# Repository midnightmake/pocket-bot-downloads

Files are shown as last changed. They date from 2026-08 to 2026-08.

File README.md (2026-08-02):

# Pocket Bot Downloads

This repository contains all of the firmware, source files, courses, and STLs files you need to get started with the [Pocket Bot](https://www.midnightmake.com/products/pocket-bot).

## Contents

* `courses`: Various line and demo courses as seen in the [example programs](https://www.midnightmake.com/pages/pocket-bot-example-programs). Courses are provided as both `.docx` and `.pdf` files. If you'd like to generate your own barcode courses, you'll want the [course-encoder repository](https://github.com/midnightmake/course-encoder).
* `firmware`: Complete source code (drivers, firmware, etc.) for the Pocket Bot, inside a [Microchip Studio](https://www.microchip.com/en-us/tools-resources/develop/microchip-studio) project file. Also a great place to start for writing your own Pocket Bot applications.
* `stls`: 3D-printable replacment and expansion parts for the Pocket Bot. Assembly instructions are available [here](https://www.midnightmake.com/pages/pocket-bot-assembly).

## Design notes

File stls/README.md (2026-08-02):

# Overview
This folder contains STL files for the Pocket Bot.

A great deal of care has gone into making these parts easily 3D-printable with 0.2mm layer heights and no supports needed. Please see more details below.

## Description

This directory contains the following files:

* `chassis.stl`: The main Pocket Bot chassis.
* `marker-mount.stl`: An optional mount for an AprilTag (or similar) that snaps onto the optional expansion header.
* `round-table.stl`: A circular table intended to show off the **Area-Keeping** [example program](https://www.midnightmake.com/pages/pocket-bot-example-programs) by not falling off.
* `wheel-for-motor.stl`: A single wheel meant to be snapped to the Pocket Bot motor axis. **For best results, print this part with TPU or another rubber-like material.**
* `wheel-for-screw.stl`: A single wheel meant to be screwed onto the Pocket Bot to freely rotate. **For best results, print this part with TPU or another rubber-like material.**

Assembly instructions are available [here](https://www.midnightmake.com/pages/pocket-bot-assembly).

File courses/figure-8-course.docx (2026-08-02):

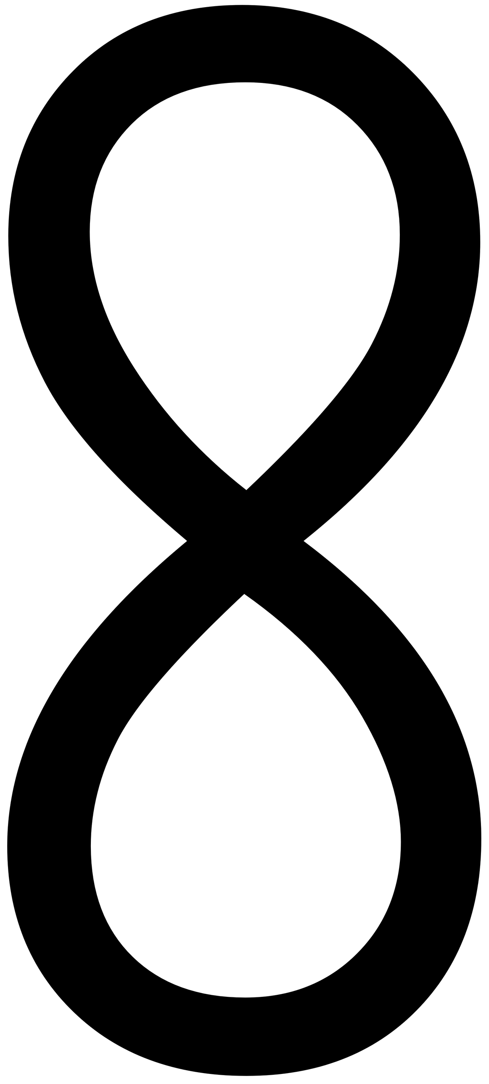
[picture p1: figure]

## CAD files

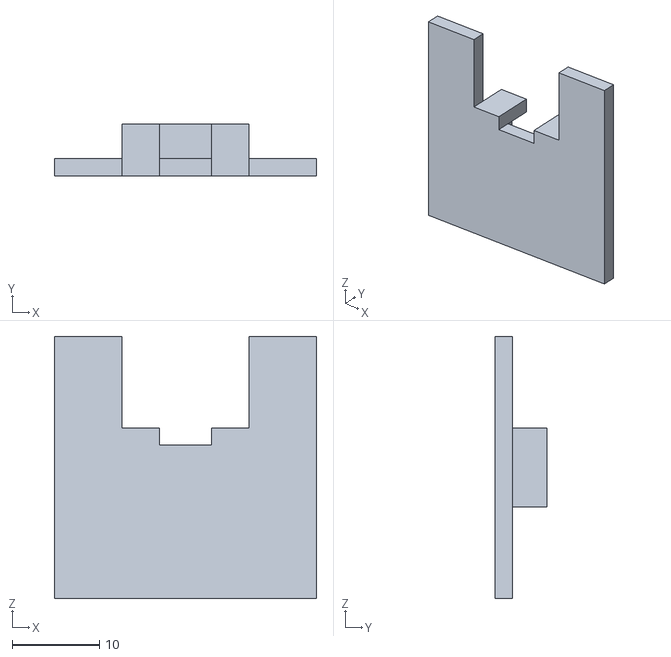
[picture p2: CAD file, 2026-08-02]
stls/marker-mount.stl
30.0 x 6.00 x 30.0

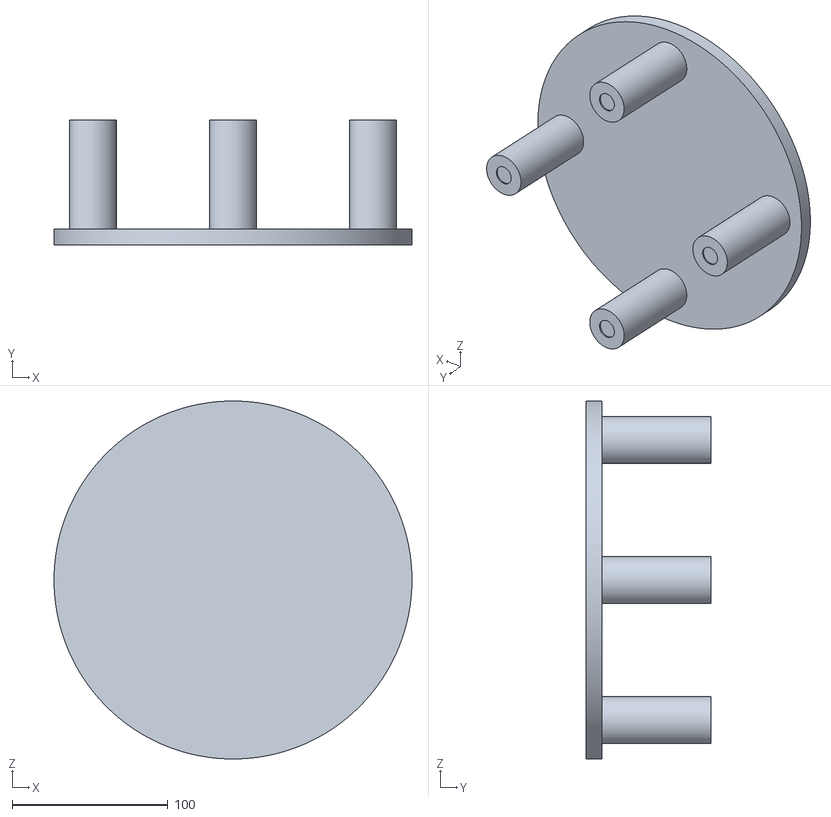
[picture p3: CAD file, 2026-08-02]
stls/round-table.stl
230.0 x 80.0 x 230.0

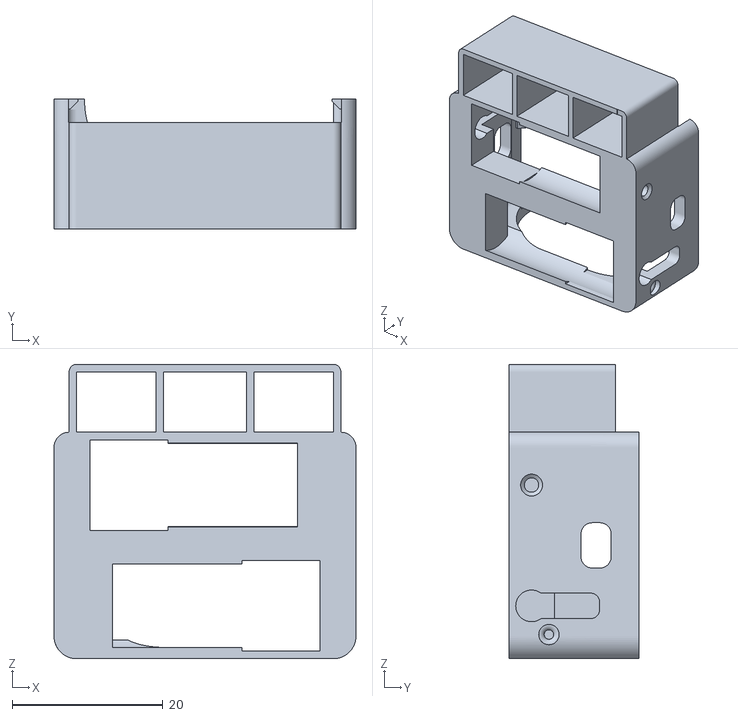
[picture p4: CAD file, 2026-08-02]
stls/chassis.stl
40.0 x 17.2 x 39.0

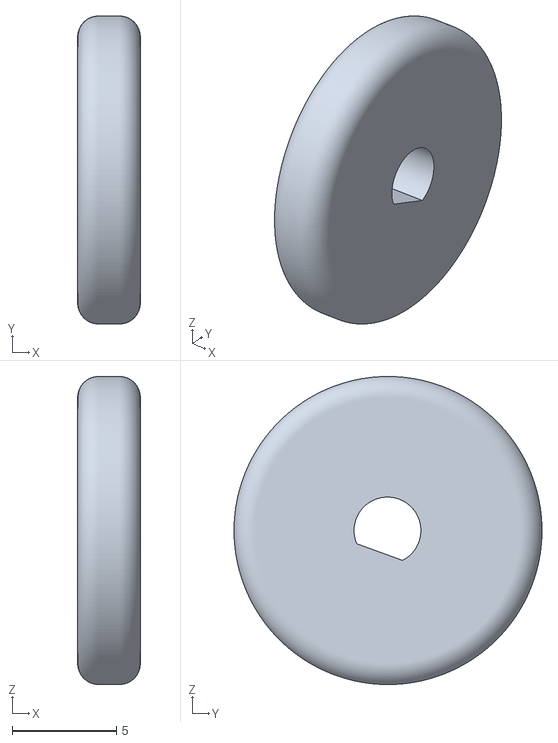
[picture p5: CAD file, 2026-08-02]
stls/wheel-for-motor.stl
3.00 x 14.7 x 14.7

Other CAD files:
stls/wheel-for-screw.stl

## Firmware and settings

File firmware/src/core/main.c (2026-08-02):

#include "drivers/clock.h"
#include "drivers/adc.h"
#include "drivers/motor.h"
#include "drivers/linesensor.h"
#include "drivers/led.h"
#include "drivers/button.h"

#include "programs/linefollowing.h"
#include "programs/fence.h"
#include "programs/barcode.h"
#include "programs/rave.h"
#include "programs/linedebug.h"
#include "programs/irforwarding.h"
#include "programs/visionclient.h"

#include "irmini/irmini.h"

#include "util/store.h"
#include "util/xabc.h"
#include "util/util.h"

#include <avr/io.h>
#include <avr/eeprom.h>

#include <util/delay.h>

#include <stdlib.h>

// - - - defines - - - //

// number of programs we can choose from; conveniently, this is equal to the number of LEDs we have available
#define NUM_PROGRAMS NUM_LEDS

// determines what length of time in milliseconds is considered a button tap vs. a hold
#define SHORT_PRESS_MS 1000

// - - - implementations - - - //

// entry point
int main(void)
{
	// program selection control
	uint8_t program;
	uint32_t buttonDownTime;
	uint8_t longPress;
	uint32_t factor;
	uint8_t red, green, blue;
	uint8_t i, j;

	// initialize core libraries
	clockInit();		// clock and timing
	xabcInit();			// pseudo-random number generator
	adcInit();			// analog-to-digital converter

	// initialize our hardware drivers
	motorInit();
	lineSensorInit();
	ledInit();
	buttonInit();

	// initialize starting LED sequence indicating setup was successful
	for(i = 0; i < 255; ++ i)
	{
		// all LEDs cycle through colours
		for(j = 0; j < NUM_LEDS; ++ j)
		{
			// compute hue for this LED at this part of the animation
			utilHue2RGB(((i + 190) * 2) + (j * 40), &red, &green, &blue);

			// compute fade in and then a fade out
			if(i < 128)
			{
				factor = (((uint32_t)i * 1000) / 128);
			}
			else
			{
				factor = (((255 - (uint32_t)i) * 1000) / 128);
			}

			// compute colour components
			red = (((uint32_t)red * factor) / 2000);
			green = (((uint32_t)green * factor) / 2000);
			blue = (((uint32_t)blue  * factor) / 2000);
			ledSet(j, red, green, blue);
			ledRefresh();
		}
	}

	// [OPTIONAL]: bypass user selection mode and start a program automatically here
	//runVisionClientProgram();

	// [OPTIONAL]: assign a robot ID on start-up if needed
	//eeprom_write_byte((uint8_t*)STORE_ID_ADDR, 17);

	// fade in first blue LED since this will always be highlighted by default
	ledClear();
	for(i = 0; i < 64; i += 2)
	{
		ledSet(0, 0, 0, i);
		ledRefresh();
		_delay_ms(10);
	}

	// set program 0 as the default
	program = 0;
	ledClear();
	ledSet(program, 0, 0, 64);
	ledRefresh();

	// [OPTIONAL]: adjust motor speeds slightly if they're imbalanced; this is very common even for expensive motors
	//motorScaleLeft(0.85f);
	//motorScaleRight(1.0f);

	// main loop; we should never exit out of this
	while(1)
	{
		// was the button pressed?
		if(buttonDown())
		{
			// start a timer
			buttonDownTime = clockMillis();
			longPress = 0;

			// debounce and wait for button to come up again
			_delay_ms(50);
			while(buttonDown())
			{
				// is it a long hold?
				if(clockMillis() - buttonDownTime > SHORT_PRESS_MS)
				{
					// show all LEDs, indicating long press is active
					for(i = 0; i < NUM_LEDS; ++ i)
					{
						ledSet(i, 0, 0, 64);
					}
					ledRefresh();

					// register as a long hold on the button
					longPress = 1;
				}
			}

			// turn off leds if they need to be
			ledClear();
			ledRefresh();

			// what kind of press was it?
			if(longPress)
			{
				// wait for user to start
				utilWaitForButtonPress(program);

				// clear LED status in preparation for upcoming program
				ledClear();
				ledRefresh();

				// start the program; we block here until the program is complete
				if     (program == 0) runLineFollowingProgram();
				else if(program == 1) runFenceProgram();
				else if(program == 2) runBarcodeProgram();
				else if(program == 3) runRaveProgram();
				else if(program == 4) runLineDebugProgram();

				// [ at this point, whatever program was running is done ]

				// stop motors
				motorLeft(0);
				motorRight(0);
			}
			else
			{
				// next program
				program = (program + 1) % NUM_PROGRAMS;
			}

			// indicate program with LEDs
			ledClear();
			ledSet(program, 0, 0, 64);
			ledRefresh();
		}

		// handle low battery indicator
		utilHandleLowPower();
	}

	// good practice to prevent execution of random code by accident
	while(1);
}

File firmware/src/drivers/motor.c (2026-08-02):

#include "drivers/motor.h"

#include <avr/io.h>

#include <util/delay.h>

#include <stdlib.h>
#include <stdint.h>

// - - - defines - - - //

#define MOTOR_1A_PORT PORTD
#define MOTOR_1A_DIR DDRD
#define MOTOR_1A_PIN 6

#define MOTOR_1B_PORT PORTD
#define MOTOR_1B_DIR DDRD
#define MOTOR_1B_PIN 5

#define MOTOR_2A_PORT PORTB
#define MOTOR_2A_DIR DDRB
#define MOTOR_2A_PIN 3

#define MOTOR_2B_PORT PORTD
#define MOTOR_2B_DIR DDRD
#define MOTOR_2B_PIN 3

#define SPEED_LIMIT 100

// - - - prototypes - - - //

void _disableLeftMotorOutputs();
void _disableRightMotorOutputs();
int8_t _computeValidSpeed(int8_t speed);
uint8_t _isDirDifferent(int8_t old, int8_t newDir);

// - - - static members - - - //

// set by the motorUseHardBrake() function
static uint8_t _useHardBrake = 1;

// we track motor speeds and direction so we can make intelligent decisions about turning
// on or off our output compare pins
static int8_t _leftSpeed = 0;
static int8_t _rightSpeed = 0;

// used to scale motor speeds if they aren't perfectly matched
static float _leftScale = 1.0f;
static float _rightScale = 1.0f;

// - - - implementations - - - //

void motorInit()
{
	// [note]: during initial testing, I've observed some cases in which motors trying to run at full speed will fail to run; I have some
	// theories about this, but we'll just avoid running the motors at a full 100% duty cycle for now; for simplicity, we just double the
	// incoming motor speeds (-100 to 100) when they're received, giving us a maximum duty cycle of 200 / 255 = 78%; we should revisit this
	// in the future if higher speeds are desired, but for now this doesn't seem to be a real issue for a small tabletop robot

	// immediately keep motor pins low
	MOTOR_1A_PORT &= ~(1 << MOTOR_1A_PIN);
	MOTOR_1B_PORT &= ~(1 << MOTOR_1B_PIN);
	MOTOR_2A_PORT &= ~(1 << MOTOR_2A_PIN);
	MOTOR_2B_PORT &= ~(1 << MOTOR_2B_PIN);

	// set motor 1 pins as outputs
	MOTOR_1A_DIR |= (1 << MOTOR_1A_PIN);
	MOTOR_1B_DIR |= (1 << MOTOR_1B_PIN);

	// set motor 2 pins as outputs
	MOTOR_2A_DIR |= (1 << MOTOR_2A_PIN);
	MOTOR_2B_DIR |= (1 << MOTOR_2B_PIN);

	// disable motor outputs
	_disableLeftMotorOutputs();
	_disableRightMotorOutputs();

	// setup timer 0 for motor 1
	TCCR0A |= (1 << WGM00) | (1 << WGM01);					// fast PWM mode with TOP defined as 0xff
	TCCR0B |= (1 << CS00) | (1 << CS02);					// initial tests show that a /1024 prescalar, while a little choppy at low duty cycles, works best
															// out of all the prescalars available to both timer 0 and timer 2

	// setup timer 2 for motor 2
	TCCR2A |= (1 << WGM20) | (1 << WGM21);					// fast PWM mode with TOP defined as 0xff
	TCCR2B |= (1 << CS20) | (1 << CS21) | (1 << CS22);		// /1024 prescalar; [note]: different registers are used for this prescalar than timer 0

	// initialize our speeds
	_useHardBrake = 1;
	_leftSpeed = 0;
	_rightSpeed = 0;
	_leftScale = 1.0f;
	_rightScale = 1.0f;
}

void motorUseHardBrake(uint8_t useHardBrake)
{
	// enable hard brake
	_useHardBrake = useHardBrake;

	// re-input motor speeds for any-zero speed motors
	if(_leftSpeed == 0) motorLeft(0);
	if(_rightSpeed == 0) motorRight(0);
}

void motorLeft(int8_t speed)
{
	// keep in valid range after applying a scaling
	speed = _computeValidSpeed((int8_t)((float)speed * _leftScale));

	// first, disable left output entirely if we've changed direction
	if(_isDirDifferent(_leftSpeed, speed))
	{
		_disableLeftMotorOutputs();
		_delay_ms(5);
	}

	// are we going forwards?
	if(speed > 0)
	{
		// set compare value and enable output compare pin for OC0A
		OCR0A = abs(speed) * 2;
		TCCR0A |= (1 << COM0A1);
	}
	// are we going backwards?
	else if(speed < 0)
	{
		// set compare value and enable output compare pin for OC0B
		OCR0B = abs(speed) * 2;
		TCCR0A |= (1 << COM0B1);
	}
	// we've stopped
	else
	{
		// brake according to braking settings
		if(_useHardBrake)
		{
			// set left motor pins high to enable hard brake
			MOTOR_1A_PORT |= (1 << MOTOR_1A_PIN);
			MOTOR_1B_PORT |= (1 << MOTOR_1B_PIN);
		}
	}

	// record current speed
	_leftSpeed = speed;
}

void motorRight(int8_t speed)
{
	// keep in valid range after applying a scaling
	speed = _computeValidSpeed((int8_t)((float)-speed * _rightScale));

	// first, disable right output entirely if we've changed direction
	if(_isDirDifferent(_rightSpeed, speed))
	{
		_disableRightMotorOutputs();
		_delay_ms(5);
	}

	// are we going forwards?
	if(speed > 0)
	{
		// set compare value and enable output compare pin for OC2A
		OCR2A = abs(speed) * 2;
		TCCR2A |= (1 << COM2A1);
	}
	// are we going backwards?
	else if(speed < 0)
	{
		// set compare value and enable output compare pin for OC2B
		OCR2B = abs(speed) * 2;
		TCCR2A |= (1 << COM2B1);
	}
	// we've stopped
	else
	{
		// brake according to braking settings
		if(_useHardBrake)
		{
			// set right motor pins high to enable hard brake
			MOTOR_2A_PORT |= (1 << MOTOR_2A_PIN);
			MOTOR_2B_PORT |= (1 << MOTOR_2B_PIN);
		}
	}

	// record current speed
	_rightSpeed = speed;
}

void motorScaleLeft(float scale)
{
	_leftScale = scale;
}

void motorScaleRight(float scale)
{
	_rightScale = scale;
}

void _disableLeftMotorOutputs()
{
	// disconnect left motor output compare pins
	TCCR0A &= ~((1 << COM0A0) | (1 << COM0A1));
	TCCR0A &= ~((1 << COM0B0) | (1 << COM0B1));

	// set left motor pins low; this puts us in coast mode
	MOTOR_1A_PORT &= ~(1 << MOTOR_1A_PIN);
	MOTOR_1B_PORT &= ~(1 << MOTOR_1B_PIN);
}

void _disableRightMotorOutputs()
{
	// disconnect right motor output compare pins
	TCCR2A &= ~((1 << COM2A0) | (1 << COM2A1));
	TCCR2A &= ~((1 << COM2B0) | (1 << COM2B1));

	// set right motor pins low; this puts us in coast mode
	MOTOR_2A_PORT &= ~(1 << MOTOR_2A_PIN);
	MOTOR_2B_PORT &= ~(1 << MOTOR_2B_PIN);
}

int8_t _computeValidSpeed(int8_t speed)
{
	if     (speed < -SPEED_LIMIT) speed = -SPEED_LIMIT;
	else if(speed > SPEED_LIMIT)  speed = SPEED_LIMIT;
	return speed;
}

uint8_t _isDirDifferent(int8_t oldVal, int8_t newVal)
{
	return (oldVal > 0 && newVal <= 0) ||
		   (oldVal < 0 && newVal >= 0) ||
		   (oldVal == 0 && newVal != 0);
}

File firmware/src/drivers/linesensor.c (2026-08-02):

#include "drivers/linesensor.h"
#include "drivers/adc.h"

#include <avr/io.h>

#include <util/delay.h>

#include <stdint.h>

// - - - defines - - - //

// the pin that controls enabling/disabling of the active IR used by the sensors
#define SENSOR_ENABLE_PORT PORTB
#define SENSOR_ENABLE_DIR DDRB
#define SENSOR_ENABLE_PIN 2

// pin for line sensor 1 (left)
#define SENSOR_1_PORT PORTC
#define SENSOR_1_DIR DDRC
#define SENSOR_1_PIN 1
#define SENSOR_1_CHANNEL 1

// pin for line sensor 2 (middle)
#define SENSOR_2_PORT PORTC
#define SENSOR_2_DIR DDRC
#define SENSOR_2_PIN 2
#define SENSOR_2_CHANNEL 2

// pin for line sensor 3 (right)
#define SENSOR_3_PORT PORTC
#define SENSOR_3_DIR DDRC
#define SENSOR_3_PIN 3
#define SENSOR_3_CHANNEL 3

// maybe the design will change in the future to allow more line sensors; who knows?
#define NUM_LINE_SENSORS 3

// number of samples we take; this is high because raw readings are noisy; increasing this
// gives smoother results, but at a slower rate
#define NUM_SAMPLES 20

// - - - implementations - - - //

void lineSensorInit()
{
	// set sensor enable pin as output, but disable it by default
	SENSOR_ENABLE_DIR |= (1 << SENSOR_ENABLE_PIN);
	SENSOR_ENABLE_PORT &= ~(1 << SENSOR_ENABLE_PIN);

	// setup sensor pins
	SENSOR_1_DIR &= ~(1 << SENSOR_1_PIN);
	SENSOR_1_PORT &= ~(1 << SENSOR_1_PIN);
	SENSOR_2_DIR &= ~(1 << SENSOR_2_PIN);
	SENSOR_2_PORT &= ~(1 << SENSOR_2_PIN);
	SENSOR_3_DIR &= ~(1 << SENSOR_3_PIN);
	SENSOR_3_PORT &= ~(1 << SENSOR_3_PIN);
}

void lineSensorRead(uint16_t *sensors)
{
	int8_t i;
	uint8_t j;

	// wipe out old values
	for(i = 0; i < NUM_LINE_SENSORS; ++ i)
	{
		sensors[i] = 0;
	}

	// do fast dummy reads to clear things out and clear our initial sensor values
	for(i = 0; i < NUM_LINE_SENSORS; ++ i)
	{
		adcSetChannel(SENSOR_1_CHANNEL + i);
		adcRead();
	}

	// accumulate samples so we can average later
	for(j = 0; j < NUM_SAMPLES; ++ j)
	{
		// turn on emitters
		SENSOR_ENABLE_PORT |= (1 << SENSOR_ENABLE_PIN);
		_delay_us(100);

		// alternate between starting at left or right sensors
		for(i = (j % 2 == 1 ? 0                        : NUM_LINE_SENSORS - 1);
			    (j % 2 == 1 ? i < NUM_LINE_SENSORS     : i >= 0);
				(j % 2 == 1 ? ++ i                     : -- i))
		{
			// switch channels, take a dummy reading, turn on the IR emitter, wait, turn off the emitter, and take the actual reading
			adcSetChannel(SENSOR_1_CHANNEL + i);
			adcRead();
			sensors[i] += adcRead();
		}

		// turn off and cool down
		SENSOR_ENABLE_PORT &= ~(1 << SENSOR_ENABLE_PIN);
		_delay_us(10);
	}
	
	// average everything out
	for(i = 0; i < NUM_LINE_SENSORS; ++ i)
	{
		sensors[i] /= NUM_SAMPLES;
	}
}
